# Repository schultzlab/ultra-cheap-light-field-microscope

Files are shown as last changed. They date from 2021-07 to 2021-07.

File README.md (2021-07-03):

# Ultra-cheap light field microscope
This is a repository for the BE3 Group Project on ultra-cheap light field microscopy under the supervision of Schultz lab at Imperial College London. It contains mainly the STL and other CAD files used to 3D print the microscope framework. We mainly used Prusa i3 MK3S printer although Ultimaker 3 was also used for a small amount of components. All parts are printed in PLA. This project was largely inspired by the  [UC2 toolbox](https://github.com/openUC2/UC2-GIT) which we shall cite here: .

This is how the system looks like in operation:
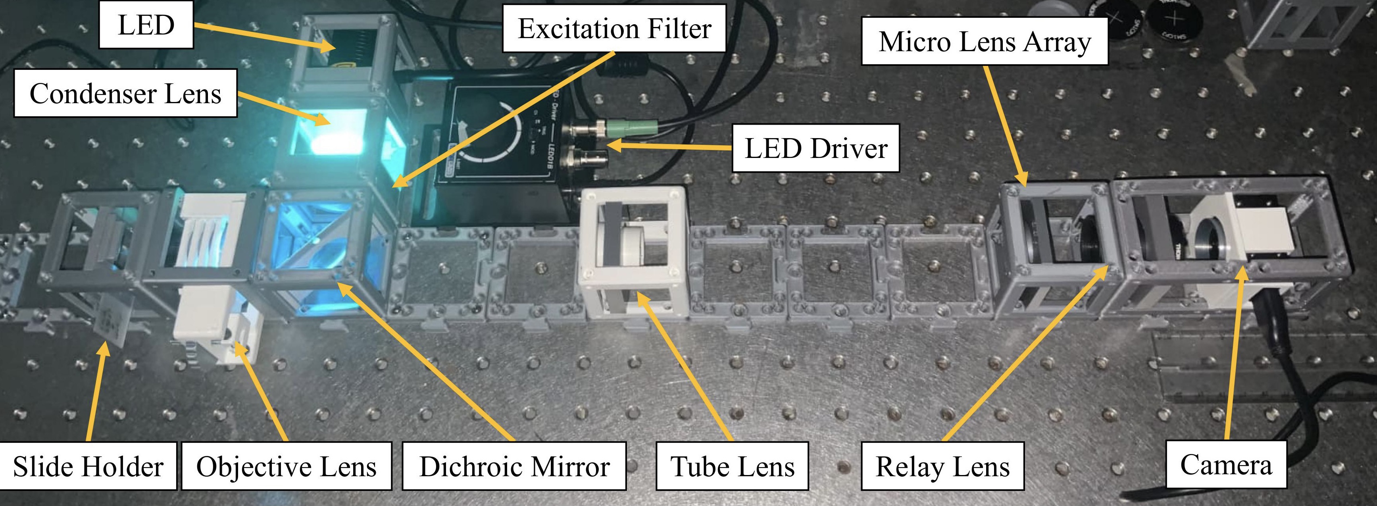
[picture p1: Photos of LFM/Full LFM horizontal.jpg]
Full LFM


# List of materials employed and composition of costs
We detail the material and cost compositions of our LFM as below.
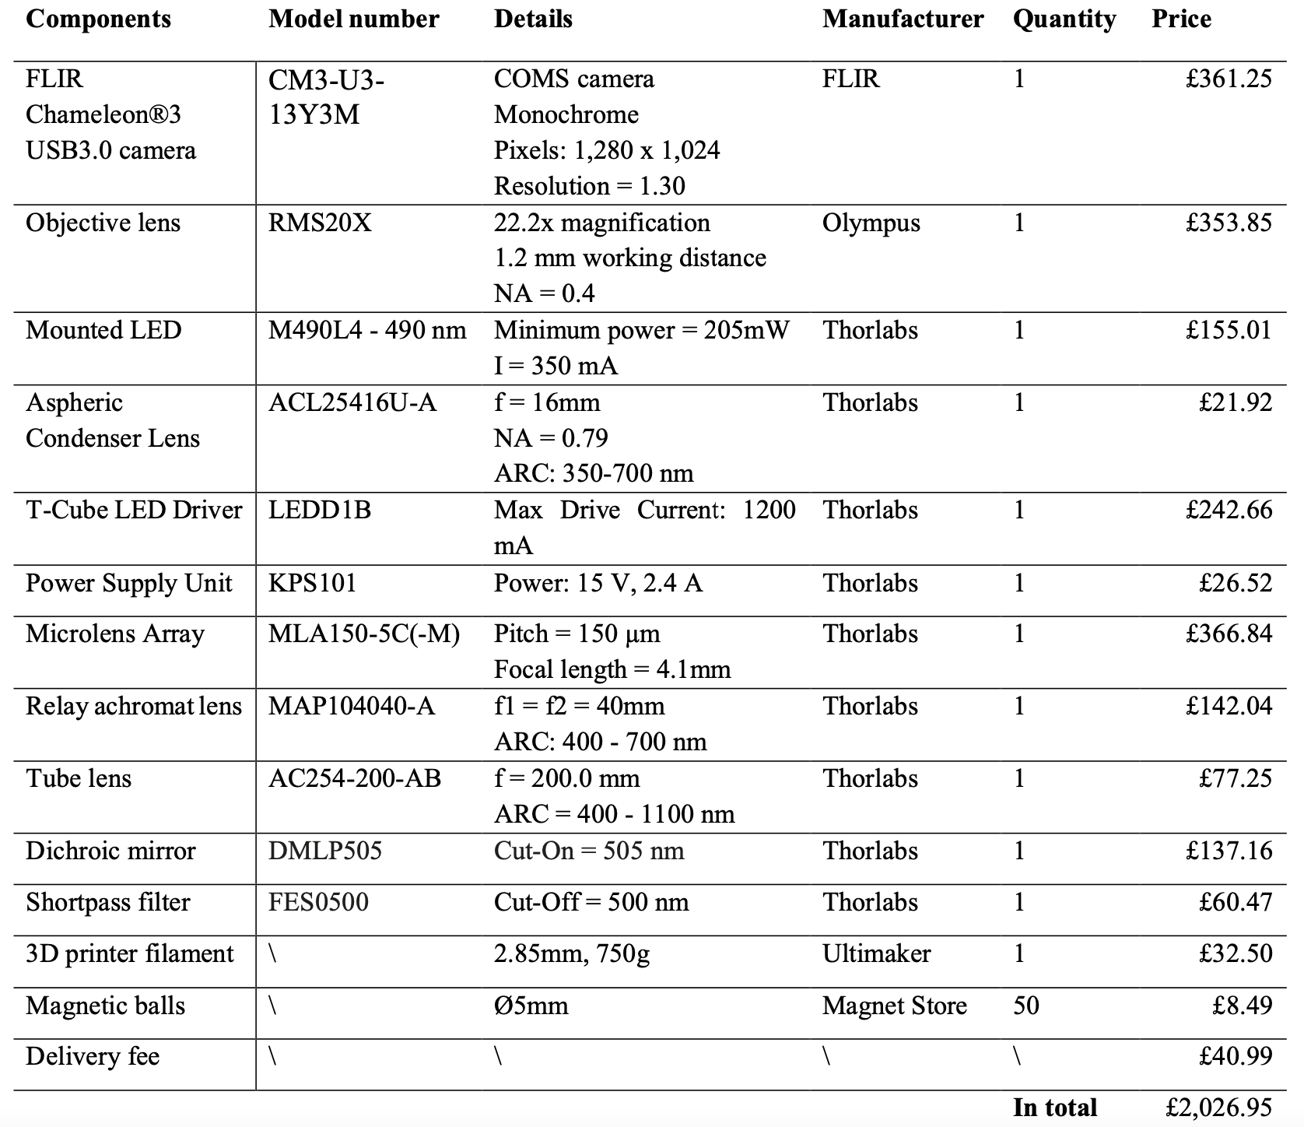
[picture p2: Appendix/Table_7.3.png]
Table_7.3


# Cost Composition
We detail and compare the cost composition of our LFM with one of the state-of-the-art LFM (Quicke et al.) as below.
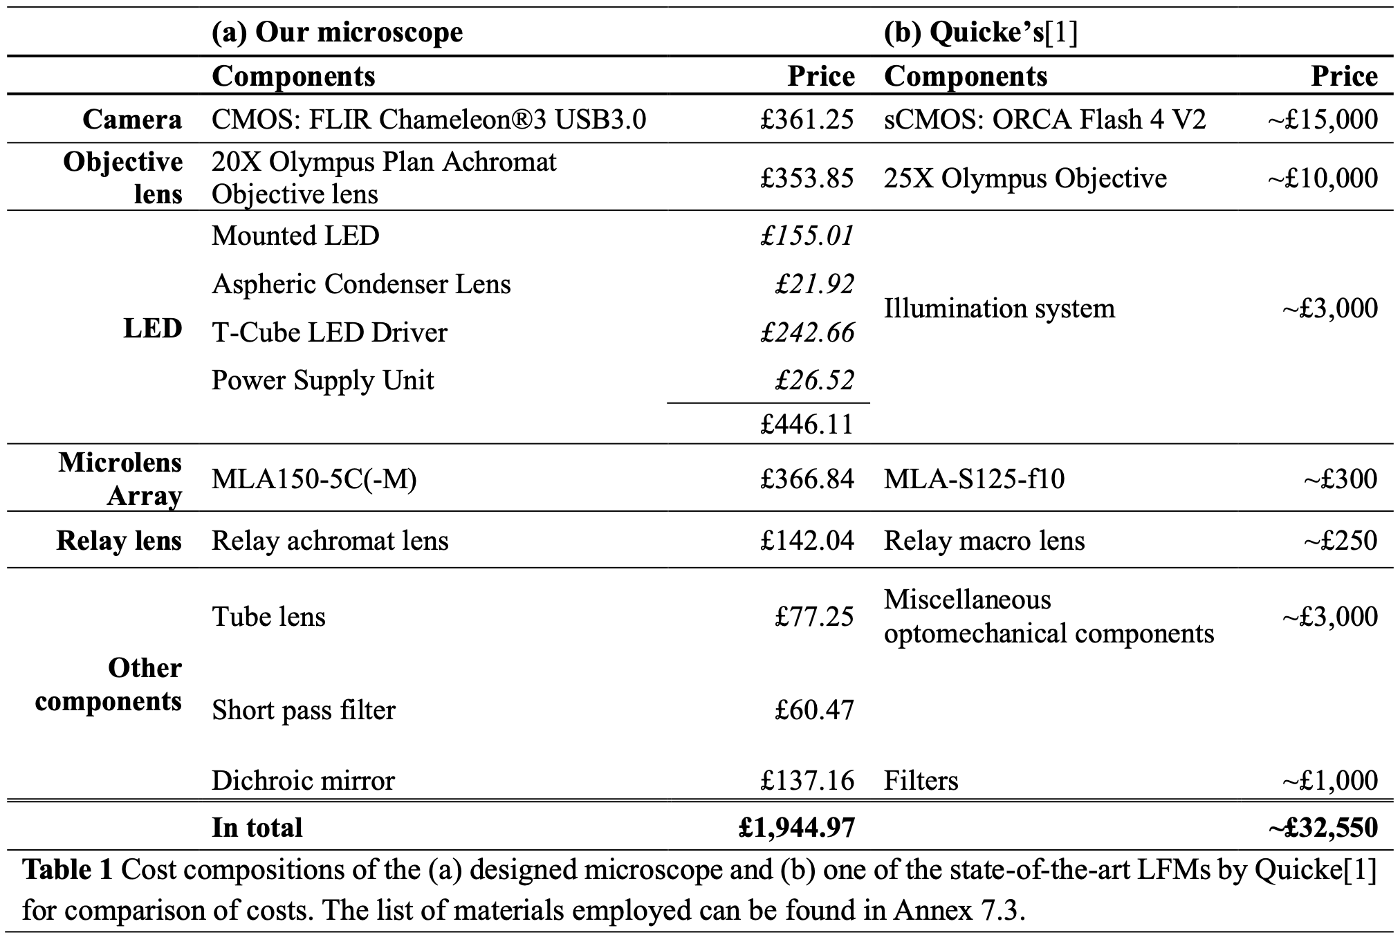
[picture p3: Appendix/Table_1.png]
Table_1


## List of modules
1. [Camera and relay lens](https://github.com/schultzlab/ultra-cheap-light-field-microscope/tree/main/Camera%20and%20relay%20lens)
2. [Dichroic mirror](https://github.com/schultzlab/ultra-cheap-light-field-microscope/tree/main/Dichroic%20mirror)
3. [LED (Illumination unit)](https://github.com/schultzlab/ultra-cheap-light-field-microscope/tree/main/LED)
4. [Microlens array (MLA)](https://github.com/schultzlab/ultra-cheap-light-field-microscope/tree/main/MLA)
5. [Objective lens and stage](https://github.com/schultzlab/ultra-cheap-light-field-microscope/tree/main/Objective%20lens)
6. [Sample stage](https://github.com/schultzlab/ultra-cheap-light-field-microscope/tree/main/Sample%20stage)
7. [Tube lens](https://github.com/schultzlab/ultra-cheap-light-field-microscope/tree/main/Tube%20lens)

## Correspondence
Any correspondence in relation to this work should be addressed to Zhiyu Zheng (zhiyu.zheng18@imperial.ac.uk), Yinzhe Wu (yinzhe.wu18@imperial.ac.uk), and/or Simon Schultz (s.schultz@imperial.ac.uk) at Imperial College London (UK)

## Cite us
We thank you for your interests in our work. This work has been published on XXX and should be cited as below.
xxx

## License
The code in this repository is licensed under the [MIT License](https://github.com/schultzlab/ultra-cheap-light-field-microscope/blob/main/LICENSE) by GitHub.

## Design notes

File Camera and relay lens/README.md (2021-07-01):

# Camera and relay lens cube
This module holds the camera and the relay lens. We used a modified 2x1 UC2 cube to allow more space for adjusting distance between the two. We used FLIR Chameleon®3 USB 3.0 Camera and Thorlabs MAP104040-A 1:1 Matched Achromatic Pair, f1=40.0 mm, f2=40.0 mm, ARC: 400-700 nm as relay lens. Note that the 20_Cube_Insert_RaspiCam_3.5mm_thick v3.stl was printed using Ultimaker 3.

Photos of the module are shown below:
Camera and relay 1
Camera and relay 2

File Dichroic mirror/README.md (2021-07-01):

# Mirror Holder Cube 

This is a Cube for holding the Dichroic mirror at 45 degree. We used DMLP505 Ø1" Longpass Dichroic Mirror, 505 nm Cut-On from Thorlabs.

After some experiments, we decided to use 45 mirror_with_hole_thin_ver v1.stl as the dichroic holder. The assembled cube looks like this:
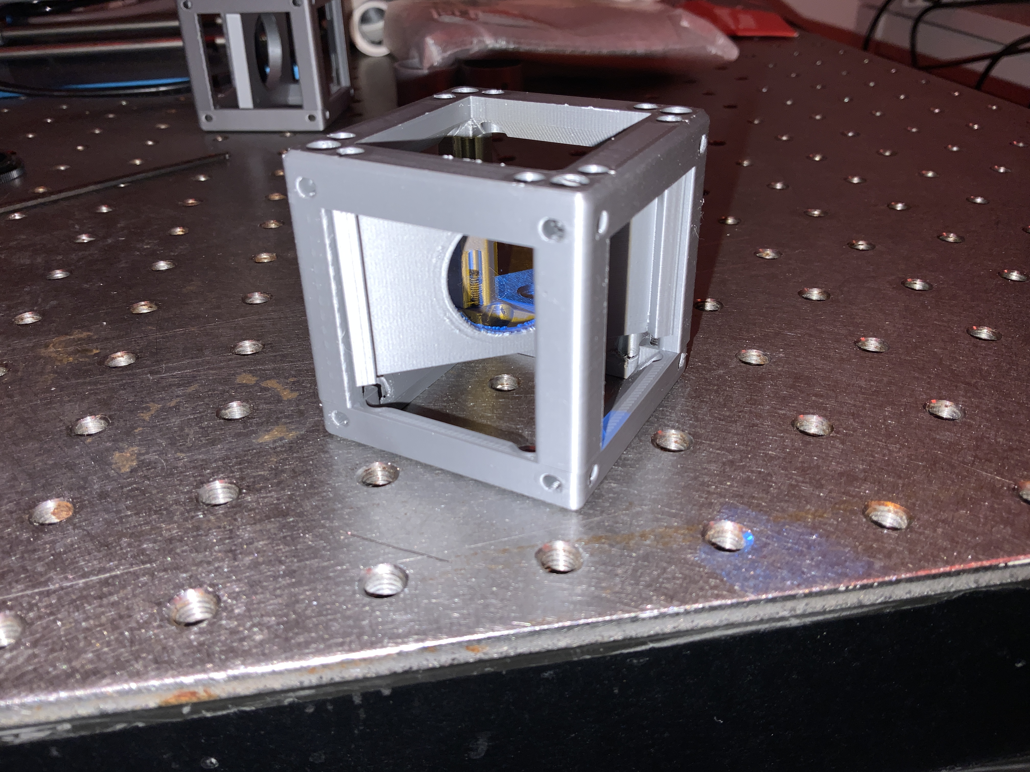
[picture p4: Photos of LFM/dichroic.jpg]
Dichroic mirror cube


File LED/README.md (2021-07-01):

# LED Holder Cube

This is a cube for holding for LED. We used the M490L4 490 nm, 205 mW (Min) Mounted LED, 350 mA and ACL25416U-A Aspheric Condenser Lens, Ø1", f=16 mm, NA=0.79, ARC: 350-700 nm from Thorlabs as the condenser. An image of the LED cube with the driver (LEDD1B T-Cube LED Driver, 1200 mA Max Drive Current, Thorlabs) and an image of the cube alone are shown below:
LED cube with the driver
LED cube

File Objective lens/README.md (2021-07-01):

# Objective Lens Holder Cube

Objective holder for Thorlabs' RMS20X - 20X Olympus Plan Achromat Objective, 0.4 NA, 1.2 mm WD, 24.0mm in diameter. The naming convention for the objective mount is UC2_20_focus_inlet_objective_mount_v8_(screw hole diameter, 32 if absent)_(bottom internal diameter)-(top internal diameter)-(external diameter).stl. For us UC2_20_focus_inlet_objective_mount_v8_30-202-242-266 v15.stl worked with Prusa i3 MK3S but different dimensions may be needed on a different 3D printer.

There is a modified UC2 Z-Stage to move the objetive along the optical axis.

Photos of module are shown below:
objective 1
objective 2

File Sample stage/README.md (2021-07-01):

# Sample stage
This cube holds the sample holder and sample clamp designed by UC2. 

A photo of the assembled module is shown below:
Sample stage

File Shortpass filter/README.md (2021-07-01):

# Shortpass Filter Cube 

This cube holds the shorpass filter. We used the FES0500 - Ø1" Shortpass Filter, Cut-Off Wavelength: 500 nm from Thorlabs.

Photos of module are shown below:
Shortpass filter

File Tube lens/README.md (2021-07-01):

# Tube Lens Cube

This module holds the tube lens for the microscope. We used AC254-200-AB f = 200.0 mm, Ø1" Achromatic Doublet, ARC: 400 - 1100 nm from Thorlabs as the tube lens. 

Photos of the assembled module are shown below:
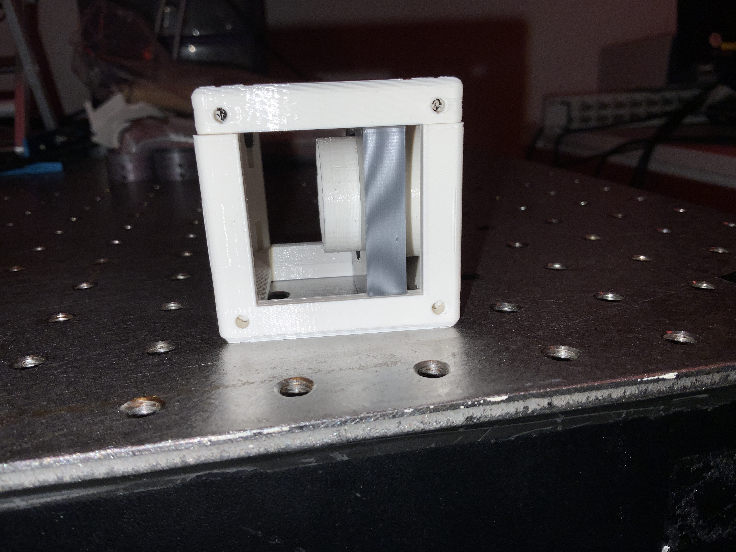
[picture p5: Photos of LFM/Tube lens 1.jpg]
Tube lens 1

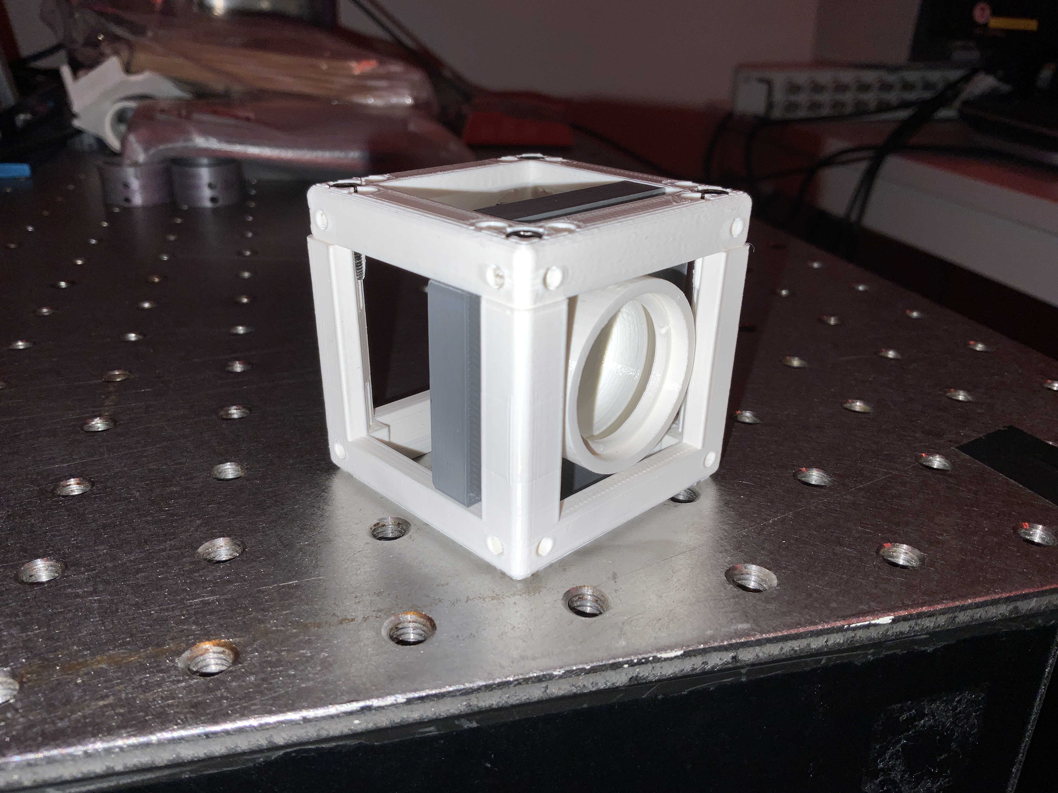
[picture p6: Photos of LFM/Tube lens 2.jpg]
Tube lens 2

Note the cube in the images was printed with Ultimaker 3, but cubes printed by Prusa i3 MK3S should also work.

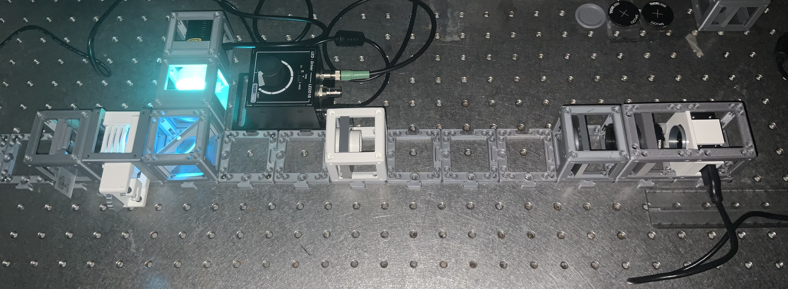
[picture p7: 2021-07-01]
Photos of LFM/Full LFM.jpg

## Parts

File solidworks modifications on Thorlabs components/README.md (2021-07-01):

# Thorlabs optomechanical components
This folder contains modified CAD files of Thorlabs optomechanical components, mainly lens holders. We 3D printed them to save costs. The original part names are indicated by the CAD file names.

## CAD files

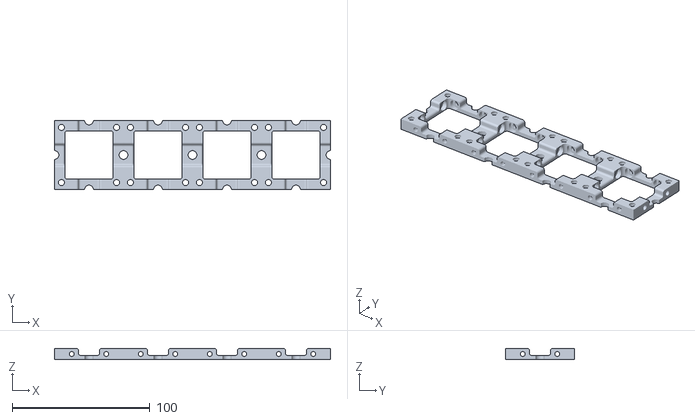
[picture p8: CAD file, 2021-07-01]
Modified UC2/Assembly_base_4x1 v1.stl
200.0 x 50.0 x 8.00

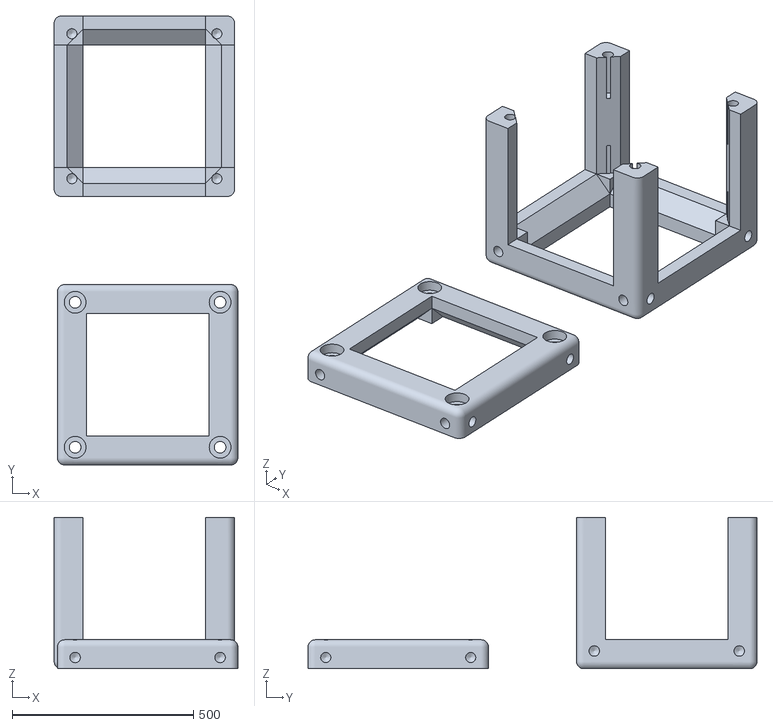
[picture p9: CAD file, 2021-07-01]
Modified UC2/10_Cube_1x1_assembly v1.stl
507.0 x 1239.0 x 418.0

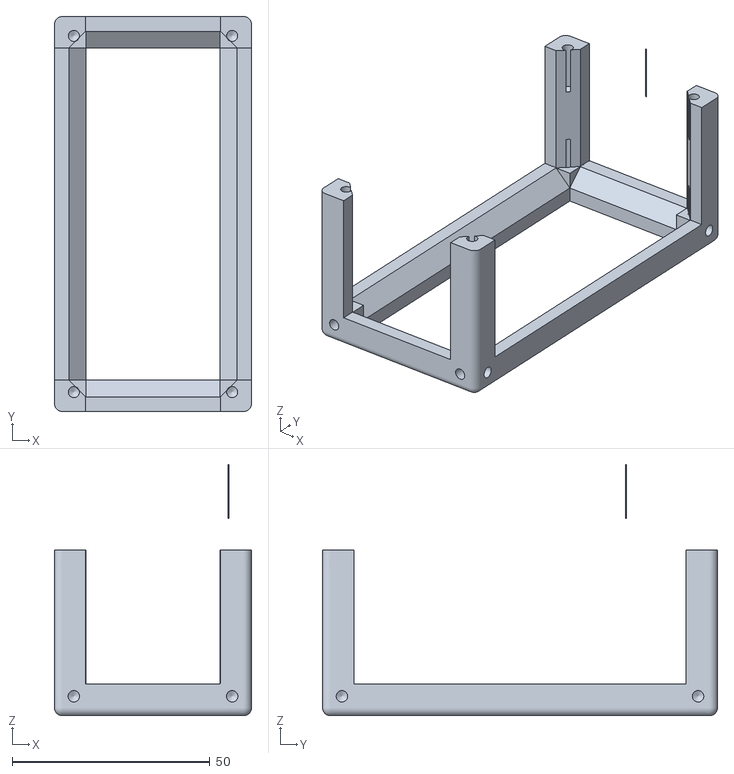
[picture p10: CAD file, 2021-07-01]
Camera and relay lens/Cube_2x1 -0.1 with 5mm holes on side face v1.stl
49.8 x 99.8 x 63.5

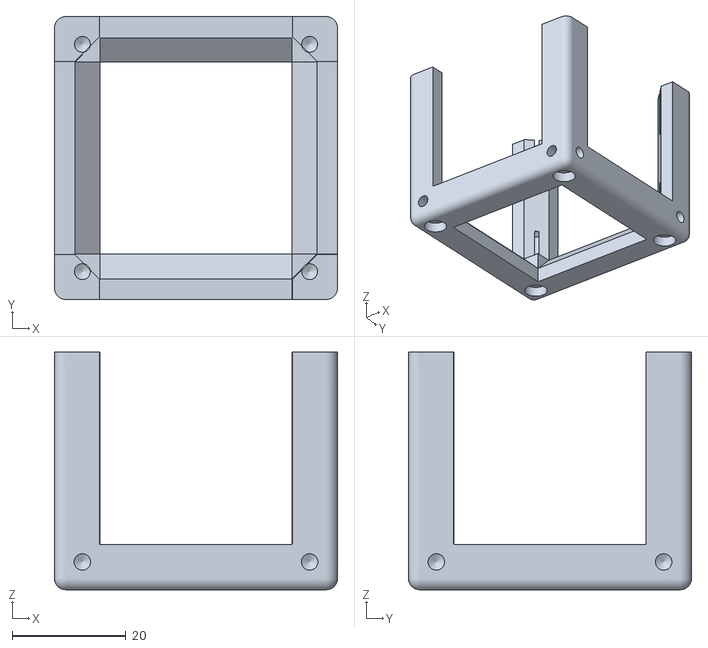
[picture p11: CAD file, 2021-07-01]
Dichroic mirror/Cube_1x1 -0.1 v1.stl
49.8 x 49.8 x 41.8

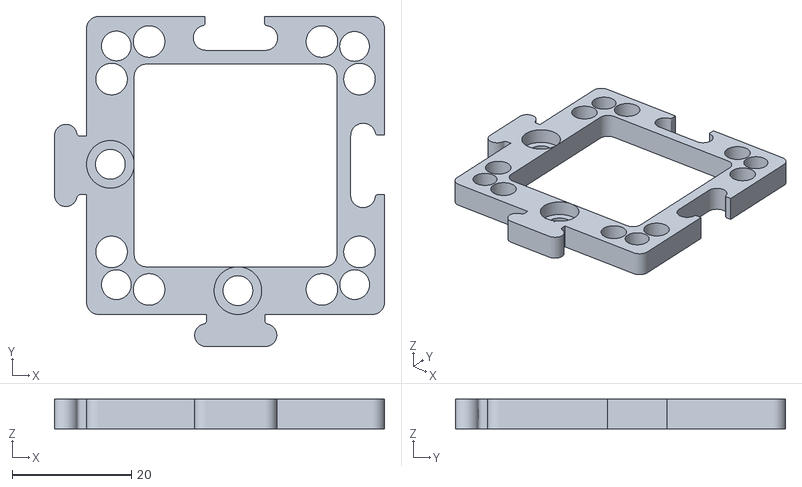
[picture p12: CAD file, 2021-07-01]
MLA/UC2_v3_10_Base_puzzle_v3 v5.stl
55.4 x 55.4 x 5.01

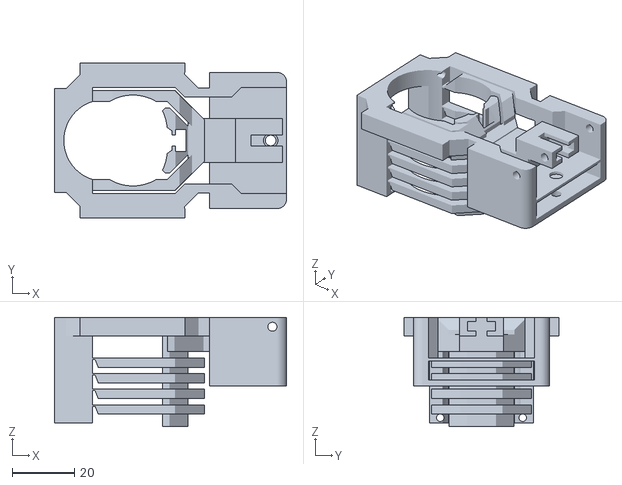
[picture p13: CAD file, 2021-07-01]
Modified UC2/new z stage.stl
74.3 x 49.8 x 35.0

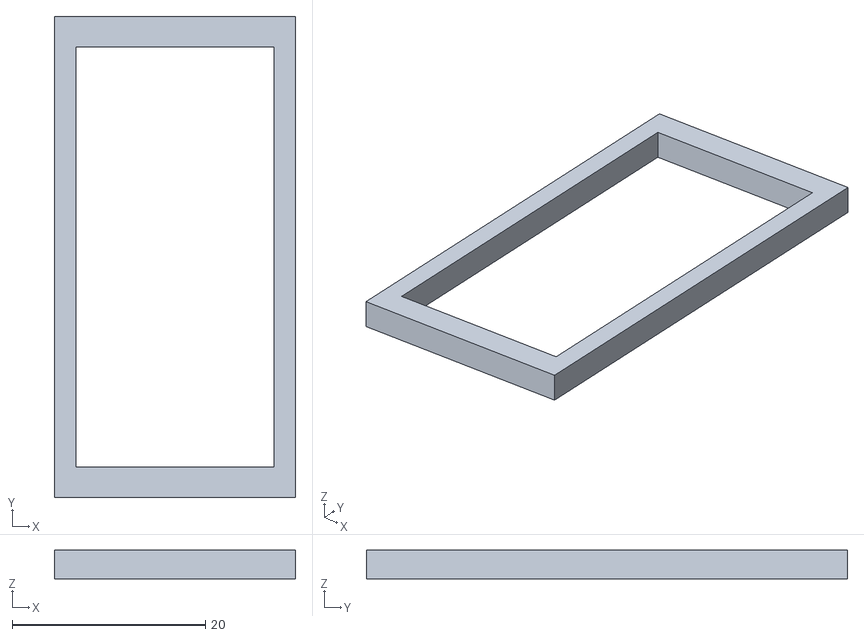
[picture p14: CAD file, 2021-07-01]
original UC2/20_Cube_Insert_Sample_clamp_v3.stl
25.0 x 49.8 x 3.00

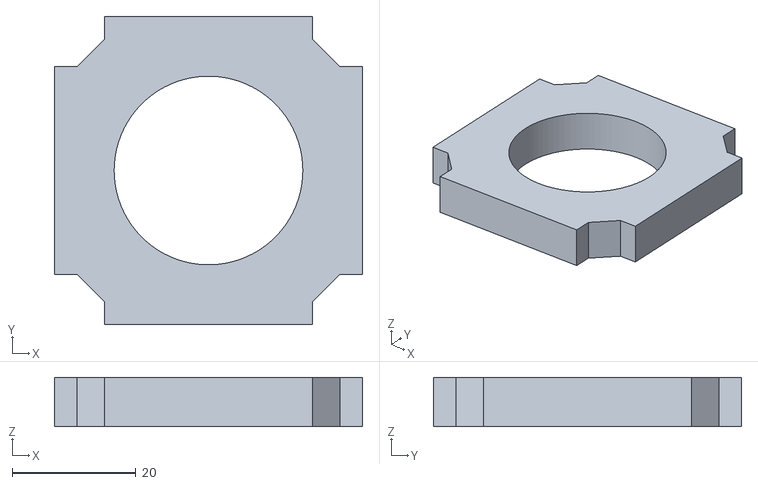
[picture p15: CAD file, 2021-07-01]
Own new parts/MountedLED30.5mm.stl
49.8 x 49.8 x 8.00

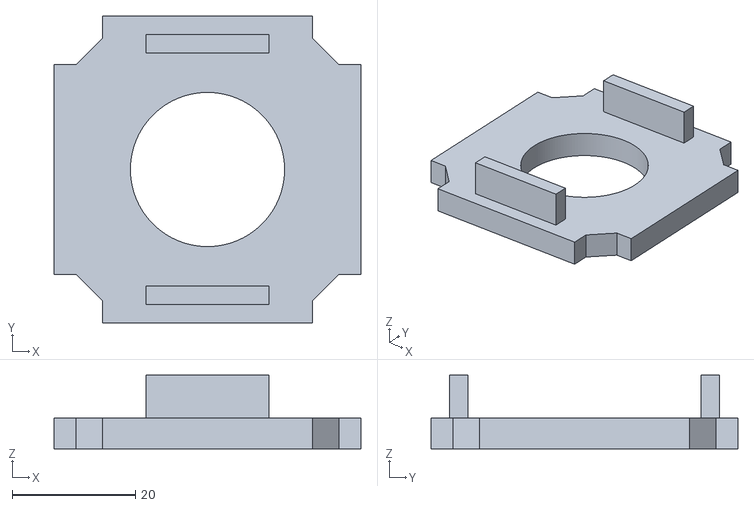
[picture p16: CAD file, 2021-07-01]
Sample stage/20_Cube_insert_Sample_holder_v3.stl
49.8 x 49.8 x 12.0

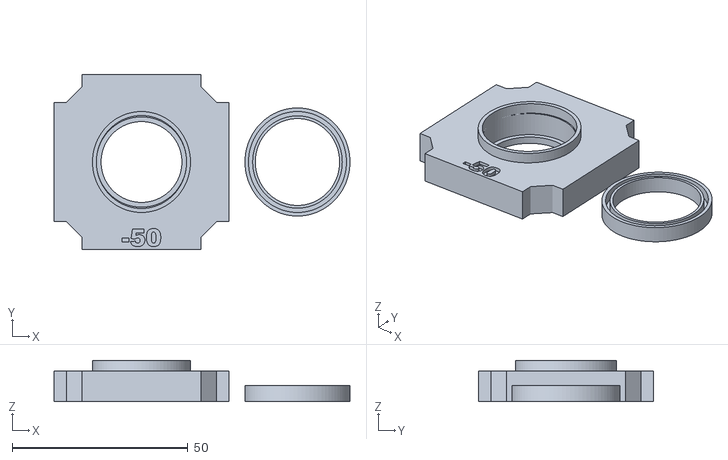
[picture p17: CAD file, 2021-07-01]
Shortpass filter/20_Insert_Lens_holder_v3_-50mm.stl
84.2 x 49.8 x 11.7

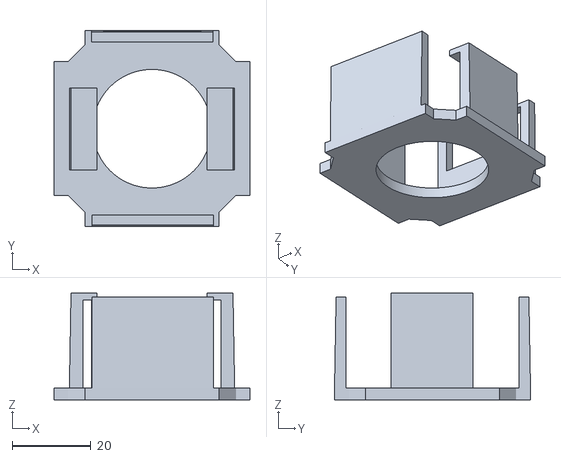
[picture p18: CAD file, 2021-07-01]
Camera and relay lens/20_Cube_Insert_RaspiCam_3.5mm_thick v3.stl
49.8 x 49.8 x 27.1

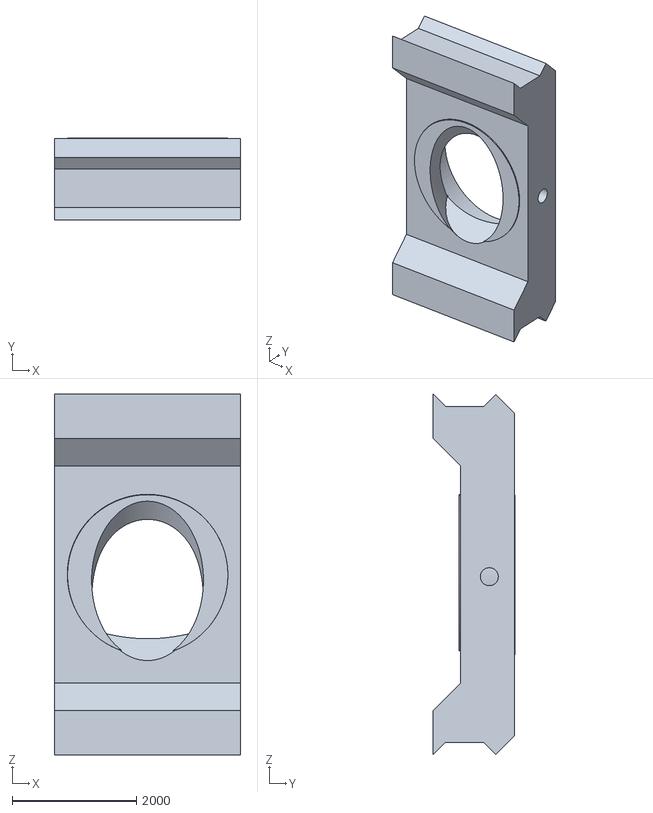
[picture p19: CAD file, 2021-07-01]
Dichroic mirror/oval mirror holder v1.stl
3001.1 x 1320.4 x 5810.2

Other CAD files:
Tube lens/MountedLED 30.8mm.stl
LED/MountedLED 31.2mm.stl
Camera and relay lens/Cube Lid_2x1_-0.2mm with 5mm holes on one side face v1.stl
Camera and relay lens/LED HOLDER expanded 8mm.stl
Dichroic mirror/45 mirror_with_hole_thin_ver v1.stl
Dichroic mirror/Cube Lid_1x1 -0.1 v3.stl
LED/Cube Lid_1x1 -0.1 v3.stl
LED/LED HOLDER expanded v2.stl
LED/MountedLED 30.6mm.stl
LED/MountedLED 30.8mm.stl
LED/MountedLED 31.0mm.stl
MLA/20_Insert_Lens_holder_v3_100mm.stl
MLA/Cube Lid_1x1 -0.1 v3.stl
Modified UC2/00_Connector_Baseplate v1.stl
Modified UC2/10_Base_v2 v2.stl
Modified UC2/10_Cube_2x1_-0.1mm_marked v1.stl
Modified UC2/10_Lid_2x1_v3 v2.stl
Modified UC2/20_Cube_Insert_Objective_Holder v4.stl
Modified UC2/20_Cube_Insert_RaspiCam2.0 v8.stl
Modified UC2/20_Cube_Insert_RaspiCam2.0 v9.stl
Modified UC2/20_Cube_Insert_Z-Focus_3.2mm v2.stl
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

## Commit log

2021-06-28 Mess added
    [00_Connector_Baseplate v1.stl, 10_Base_v2 v1.stl, 10_Base_v2 v2.stl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]
2021-06-28 Deleted redundant files
    [10_Base_v2 v1.stl, 20_Cube_Insert_Objective_Holder v3.stl, 20_Cube_Insert_RaspiCam2.0 v3.stl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]
2021-06-28 Create Camera
2021-06-29 New classification
    [20_Cube_Insert_RaspiCam_3.5mm_thick v3.stl, 20_focus_inlet_linearflexure_v1_Adjusted 0.4mm v1.stl, 45 mirror_with_hole_thin_ver v1.stl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]
2021-06-29 Further classifications
    [20_Cube_Insert_Sample_clamp_v3.stl, 20_Cube_insert_Sample_holder_v3.stl, 20_Insert_Lens_holder_v3_-50mm.stl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]
2021-06-30 Added more original UC2 files
    [20_Cube_Insert_Sample_clamp_v3.stl, 20_Cube_insert_Sample_holder_v3.stl]
